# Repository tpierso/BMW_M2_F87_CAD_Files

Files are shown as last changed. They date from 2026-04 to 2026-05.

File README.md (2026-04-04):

# BMW_M2_F87_CAD_Files
CAD files used to create custom parts for my 2018 BMW M2

DISCLAIMER:

These sample models are provided for the purpose of illustration only and is not intended to be used in a production environment.
THESE SAMPLE MODELS AND ANY RELATED INFORMATION ARE PROVIDED "AS IS" WITHOUT WARRANTY OF ANY KIND, EITHER EXPRESSED OR IMPLIED, INCLUDING BUT NOT LIMITED TO THE IMPLIED WARRANTIES OF MERCHANTABILITY AND/OR FITNESS FOR A PARTICULAR PURPOSE.

We grant You a nonexclusive, royalty-free right to use and modify the Sample Models and to reproduce and distribute the object models form of the Sample Models, provided that You agree: (i) to not use Our name, logo, or trademarks to market Your software product in which the Sample Model is embedded; (ii) to include a valid copyright notice on Your software product in which the Sample Model is embedded; and (iii) to indemnify, hold harmless, and defend Us and Our suppliers from and against any claims or lawsuits, including attorneys' fees, that arise or result from the use or distribution of the Sample models.

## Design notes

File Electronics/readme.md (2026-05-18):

# Description 
Fuse and relay mount is made to hold a Bussman 15713-24-12-22A Rear Terminal ATC Fuse Block and a GEP Power Products PDM-R3BA1, (3) Mini ISO Relay Power Distribution Module. This can support up to 200A of fuses and multiple Mini ISO relays. 

The fuse and relay box mount is made to fit the rear passenger side trunk well where the GHAS module is typically mounted on a stock car. The idea with this is you can mount the base, do all your electronics work, and then bolt the mount in (or take it out to add devices later). 

# Parts List
> [!Note]
> Keep in mind the links below will redirect to a 3rd party vendor site.

| Quantity | Part Name and Link| Notes |
| --- | --- | --- |
| 1 | [GEP Power Products Relay Box](https://www.waytekwire.com/product/gep-power-products-pdm-r3ba1-3-mini) | This allows you to run larger power relays to accomodate bigger accessories |
| 1 | [Bussman ATC Fuse Box](https://www.waytekwire.com/product/eaton-s-bussmann-series-15713-24-12-22a-rear) | This may also match bolt alignment for other Eaton boxes as well. | 
| 4 | [M5x 0.8 x 20mm Flat Head bolt](https://www.mcmaster.com/products/screws/length~20-mm/fastener-head-type~flat/thread-size~m6-2/) | |
| 2 | [M6x 1.0 x 20mm Flat Head bolt](https://www.mcmaster.com/products/screws/thread-size~m5/length~20-mm/fastener-head-type~flat/) | |
| 4 | [M5 x 0.8 x 70mm Flat bolt](https://www.mcmaster.com/products/screws/flat-head-screws-2~/thread-size~m5/length~70-mm/drive-style~hex/countersink-angle~90/thread-pitch~0-8-mm/) | A 65mm may also fit, but I just opted to go for a bigger bolt |
| 4 | [M5 x 0.8 x 5.7mm Heat Set Threaded Insert for plastic](https://www.mcmaster.com/94459A797/) | There are soldering iron adapters that work for these from [CNCKitchen] (CNCKitchen.com).  
| 2 | [M6 x 1.0mm Flange Nut](https://www.mcmaster.com/products/nuts/flange-nuts-4~/nut-type~flange/thread-size~m6-2/flange-diameter~14-25-mm/flange-diameter~14-mm/flange-diameter~14-2-mm/flange-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) | | 
| 400g~| 3D printer filament | I used Prusament PA11 CF with 20% Gyroid infill with a 4mm parameter. | |
| 20 | [Aptiv Pack-Con III Loose Female terminal](https://www.waytekwire.com/product/aptiv-12020400-pack-con-female-loose-terminal) | this is the 12-10 link, but they make multiple AWG connectors--this is for the fuse box specifically | 
| 15 | [Aptiv 630 Series Metri-Pak Female loose terminal](https://www.waytekwire.com/catalog/connectors/aptiv-metri-pack-630-series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) | this is for the relay box--again match to your wire AWG | 

# Recommended Vendors
> [!Note]
>  I'm not affliated or sponsored with these companies, but they've been good to work with and hopefully it saves you some time finding the right parts for your project.

| Vendor Name and Link| Notes |
| --- | --- |
| [KSV Looms](ksvlooms.com) | for my wiring, terminals, heat shrink, tools, and other items used in my build. Teddy ships fast and has really good communication. |
| [Prowire USA](prowireusa.com) | for anything motorsports or tooling that KSV Looms didn't carry (their shipping takes longer and their website is kind of gross to navigate). |
| [McMaster-Carr](McMaster.com) | for hardware has been good for US buyers. Their website rules and has fast shipping. |
| [WaytekWire.com](WaytekWire.com) | is where I found the fuse and relay box (linked below). Great resource for everything I couldn't find elsewhere (630 metri-pak connectors, wire seals) |
| [Mouser.com](mouser.com) |  for everything else that's odd--for example, 20-22 Metri-Pak 630 female connectors that work with wire seals. |

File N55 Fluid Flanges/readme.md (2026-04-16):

Disclaimer: https://github.com/tpierso/BMW_M2_F87_CAD_Files/blob/main/README.md

Custom ORB adapters that will mate up to the N55 engine. 

Specifically the turbo coolant outlet and the oil drain port. 

I made the coolant flange to adapt to a -06 AN ORB fitting--this file was recently updated to have provisions for the o-ring boss machine work; however, its worth noting to your machinest that the threaded area is set to the nominal diameter which means if it was machined straight up, it wouldn't have enough material to thread the 3/8-24. 

The oil drain flange does not have any o-ring boss grooves in the file; I just mentioned to my machinist to machine the o-ring boss.

Both fit to the engine perfectly; but you would want to speak to your machinist about adding the appropriate o-ring boss or machining for what fitting you plan to use.

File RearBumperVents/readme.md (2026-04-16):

Disclaimer: https://github.com/tpierso/BMW_M2_F87_CAD_Files/blob/main/README.md

For BMW "Speedhole" style vents for the rear bumper. 

I created these so they can be 3D printed, sent to a vendor like SendCutSend, or an alternative. 

The rear bumper vent surround and vent mesh are two seperate files to give you options if you want to have different materials--e.g. I have my mesh made out of aluminum anodized black with carbon fiber surrounds. 

The vent install tool is meant to be used to install the completed vents into the bumper; however, you can also combine the rear bumper vent surround and the install tool to make a cut template as well. 

I also split the install tool into 3 seperate vents for smaller 3D printers. It has a simple dovetail so you can quickly glue it together to suit what you need.

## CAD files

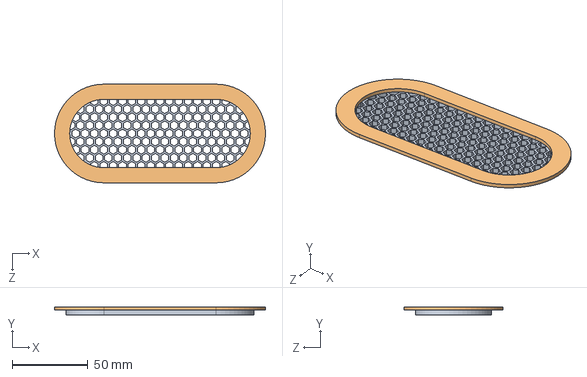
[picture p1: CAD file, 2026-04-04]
RearBumperVents/VentAssembly_mk2.STEP
139.0 x 5.01 x 65.0 mm
RearBumperVent_Mesh_mk2
RearBumperVent_mk2

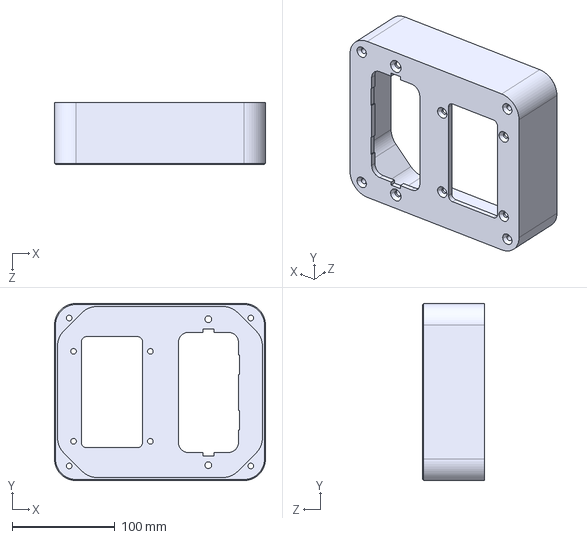
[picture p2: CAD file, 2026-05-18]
Electronics/Fuse-Relay-Box-Mount.STEP
205.2 x 172.3 x 60.0 mm

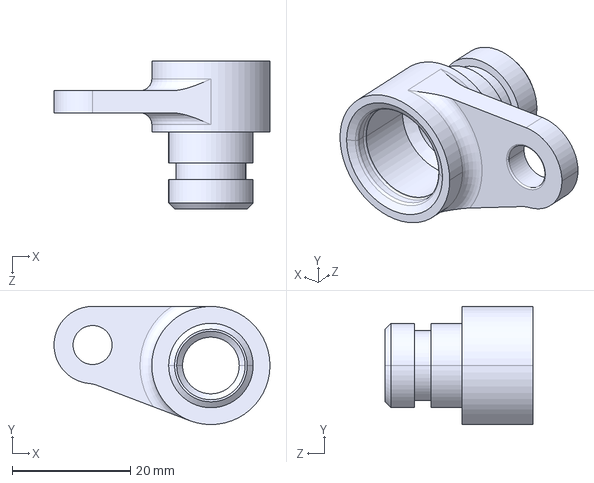
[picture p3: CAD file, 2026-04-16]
N55 Fluid Flanges/N55_Turbo_Coolant_Flange_mk2.STEP
36.6 x 20.0 x 25.0 mm

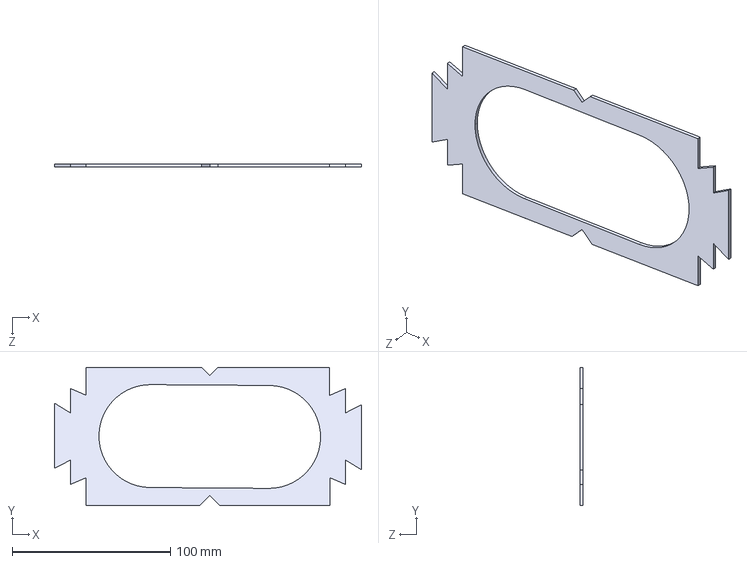
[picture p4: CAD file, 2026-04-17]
RearBumperVents/Vent_Install_Tool-Center.STEP
193.9 x 87.5 x 2.00 mm

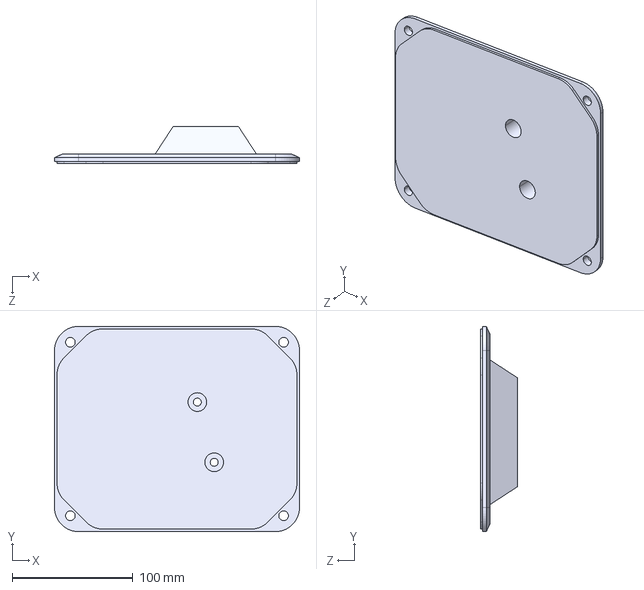
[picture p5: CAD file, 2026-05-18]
Electronics/Fuse-Relay-Box-Base.STEP
203.2 x 170.3 x 31.0 mm

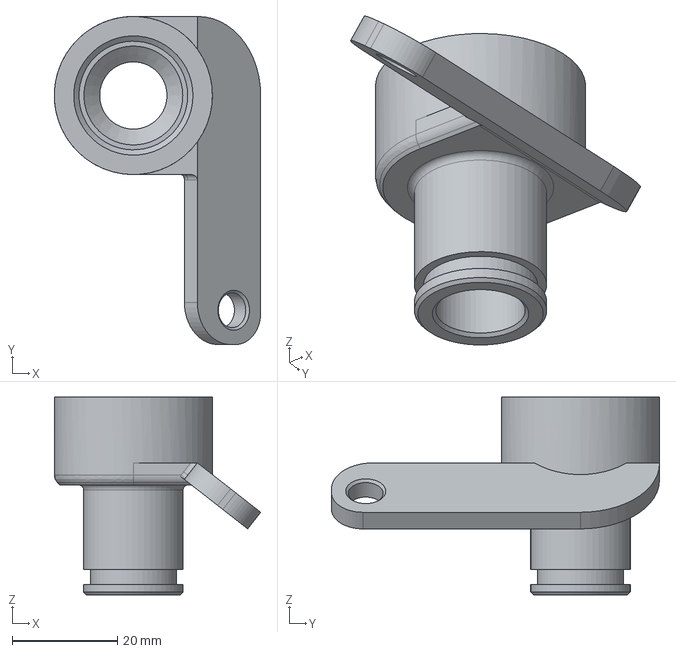
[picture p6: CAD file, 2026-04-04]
N55 Fluid Flanges/n55_oil_drain_Flange_mk8-4.step
39.2 x 62.2 x 37.5 mm

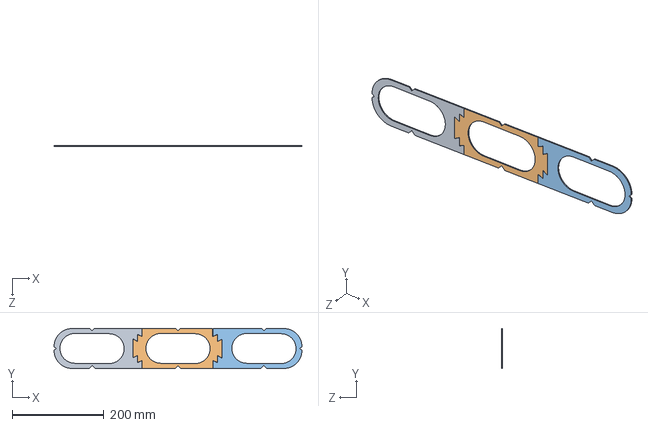
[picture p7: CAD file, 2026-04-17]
RearBumperVents/Vent_Install_Tool.STEP
541.0 x 87.5 x 2.00 mm

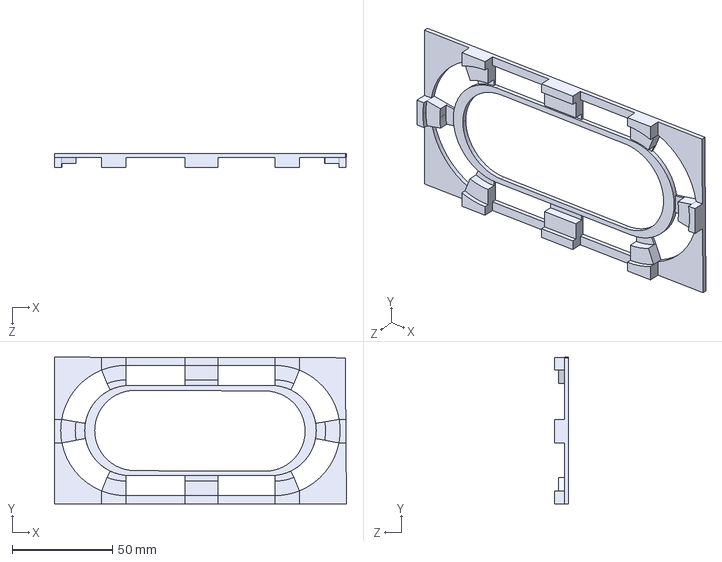
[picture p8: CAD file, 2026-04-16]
RearBumperVents/Vent_Alignment_Tool.STEP
145.8 x 73.2 x 7.00 mm

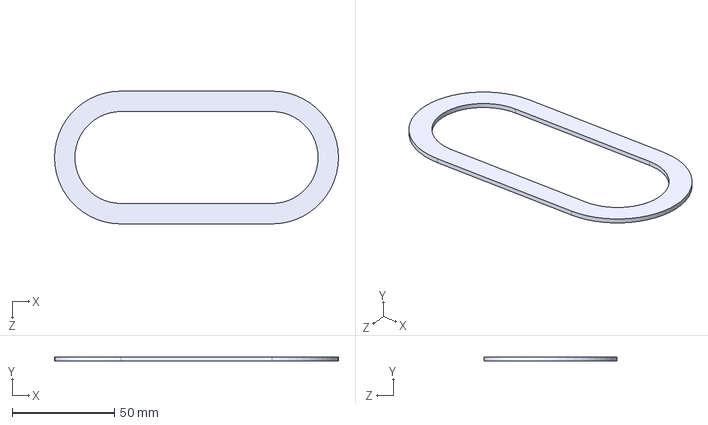
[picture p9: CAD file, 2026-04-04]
RearBumperVents/RearBumperVent_mk2.STEP
139.0 x 2.01 x 65.0 mm

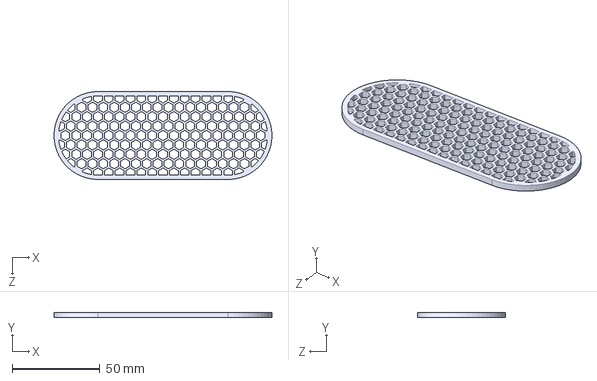
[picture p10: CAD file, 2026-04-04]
RearBumperVents/RearBumperVent_Mesh_mk2.STEP
124.0 x 3.00 x 50.0 mm

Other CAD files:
RearBumperVents/Vent_Install_Tool-Right.STEP
RearBumperVents/Vent_Install_Tool-Left.STEP

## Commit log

2026-04-04 Include disclaimer for CAD file usage
    Added a disclaimer regarding the use of CAD files.
2026-04-04 Resolved geometry issues with original vent design
    [RearBumperVent_mk2.STEP, VentAssembly_mk2.STEP]
2026-04-16 Update readme with details on rear bumper vents
    Added detailed information about the rear bumper vents, including usage and material options.
2026-05-18 Add files via upload
    Added Fuse and relay boxes
    [Fuse-Relay-Box-Base.STEP, Fuse-Relay-Box-Mount.STEP]
2026-05-18 Enhance readme with description and parts list
    Added a detailed description of the fuse and relay mount, including its purpose and installation location. Updated the parts list with specific components and links for assembly.
